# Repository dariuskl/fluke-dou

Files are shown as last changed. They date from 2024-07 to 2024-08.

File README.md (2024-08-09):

# Data Output Units for Vintage Fluke Meters

This is a collection of firmware and PCBs mean to be used in vintage Fluke
meters such as the 8000A, 1900A, etc. They provide the measurements of the
meter on a USB serial port and might also provide other features such as
the possibility to power the meter via that USB port.

The firmware targets the MSP430G2xx series of microcontrollers despite them
being neither vintage nor 5 V devices. They were chosen due to their good
availability, ease-of-use, good compiler support, wide range of package
options (including DIP), and affordability. (Most modern 5V parts just have
internal regulators anyway, due to modern lithography, so we' just be saving
us the level shifting, but some devices require more than a level shifter
anyway.)

Code is written in C, decode logic and platform-specific stuff is separated
as much as possible. So porting this to a different controller should be
straight-forward. The build is run by `make` as a jumbo build.

## 1900A — Multi-Counter

- PCB is already designed
- C++ code exists, also ported here, but not yet tested

See https://github.com/dariuskl/fluke_1900a_usb_dou

## 8000A — Digital Multimeter

**Firmware** — first working version available with tag `8000a-fw-1`
**Hardware** — PCB not yet designed, working on perfboard prototype

The 8000A is a very early multimeter with limited data output capabilities. It
offers only signals for the digits, none for the decimal point or range and
mode information.

The serial output is default configured to 19200 baud 7N1 and transmits the
readings as outlined below.

    <overload><polarity><MSD><2SD><3SD><LSD>\r\n

### Modifications Required for Battery Pack (Option -01)

The battery pack PCB does not have routing for all signals required by the DOU
onto the finger connector. The two-layered board just could not accommodate
both the traces required for the batteries and the DOU. This can be fixed with
a few jumper wires, though.

**TODO: insert a schema showing what points to connect here**

### Finger Connector Pinout

The finger conector is a card edge connector at the back of the main PCB. It
is double-sides, i.e. there might be different signals on the top and bottom
side of the board. Most handily, the Fluke engineers put some pracitcal vias
with a 2.54 mm pitch through ten of those connections, plus one extra via to
the side, but perfectly in grid. This is where a 11-position pin receptable
will find its place.

The signal `nT` is actually not part of the finger connector, but it does have
a strategically placed via. As it is next to pin 1 of the finger connector, I
assigned it the pin number zero.

Not all signals have suitable logic levels to interface to a 5 V µC (let alone
the 3.3 V MSP430), so comparators are used to condition the signals according
to the thresholds that I determined for each signal.

(Note that the given high and low voltage levels are ballpark figures.)

| Pin | Signal | Description | Low level | High level  | Threshold |
|-----|---|---|---|---|---|
| 0 | nT | Measurement period | 1.2 V | 4.8 V | 2.5 V |
| 2 | nZERO  | ??? | | | |
| 4 | S1 | MSD strobe | 0 V | 4.6 V | 2.5 V |
| 6 | S4 | LSD strobe | 0 V | 3.3 V | 1.6 V |
| 8 | S | Strobe clock | 0 V | 2.5...4.6 V | 1.6 V |
| 10  | +5V | Regulated 5V rail  | — | — | — |
| 12  | GND | Ground | — | — | — |
| 14  | Y | BCD 4 | 0 V | 4.9 V | 2.5 V |
| 16  | X | BCD 2 | 0 V | 4.9 V | 2.5 V |
| 18  | W | BCD 8 | 0 V | 4.9 V | 2.5 V |
| 20  | Z | BCD 1 | 0 V | 4.9 V | 2.5 V |

### Protocol

| Digit | W | X | Y | Z | Strobe |
|---|---|---|---|---|---|
| DS1 (MSD) | overload | ? | polarity | MSD | S1 |
| DS2..DS3  | BCD 8 | BCD 4 | BCD 2 | BCD 1 | none |
| DS4 (LSD) | BCD 8 | BCD 4 | BCD 2 | BCD 1 | S4 |

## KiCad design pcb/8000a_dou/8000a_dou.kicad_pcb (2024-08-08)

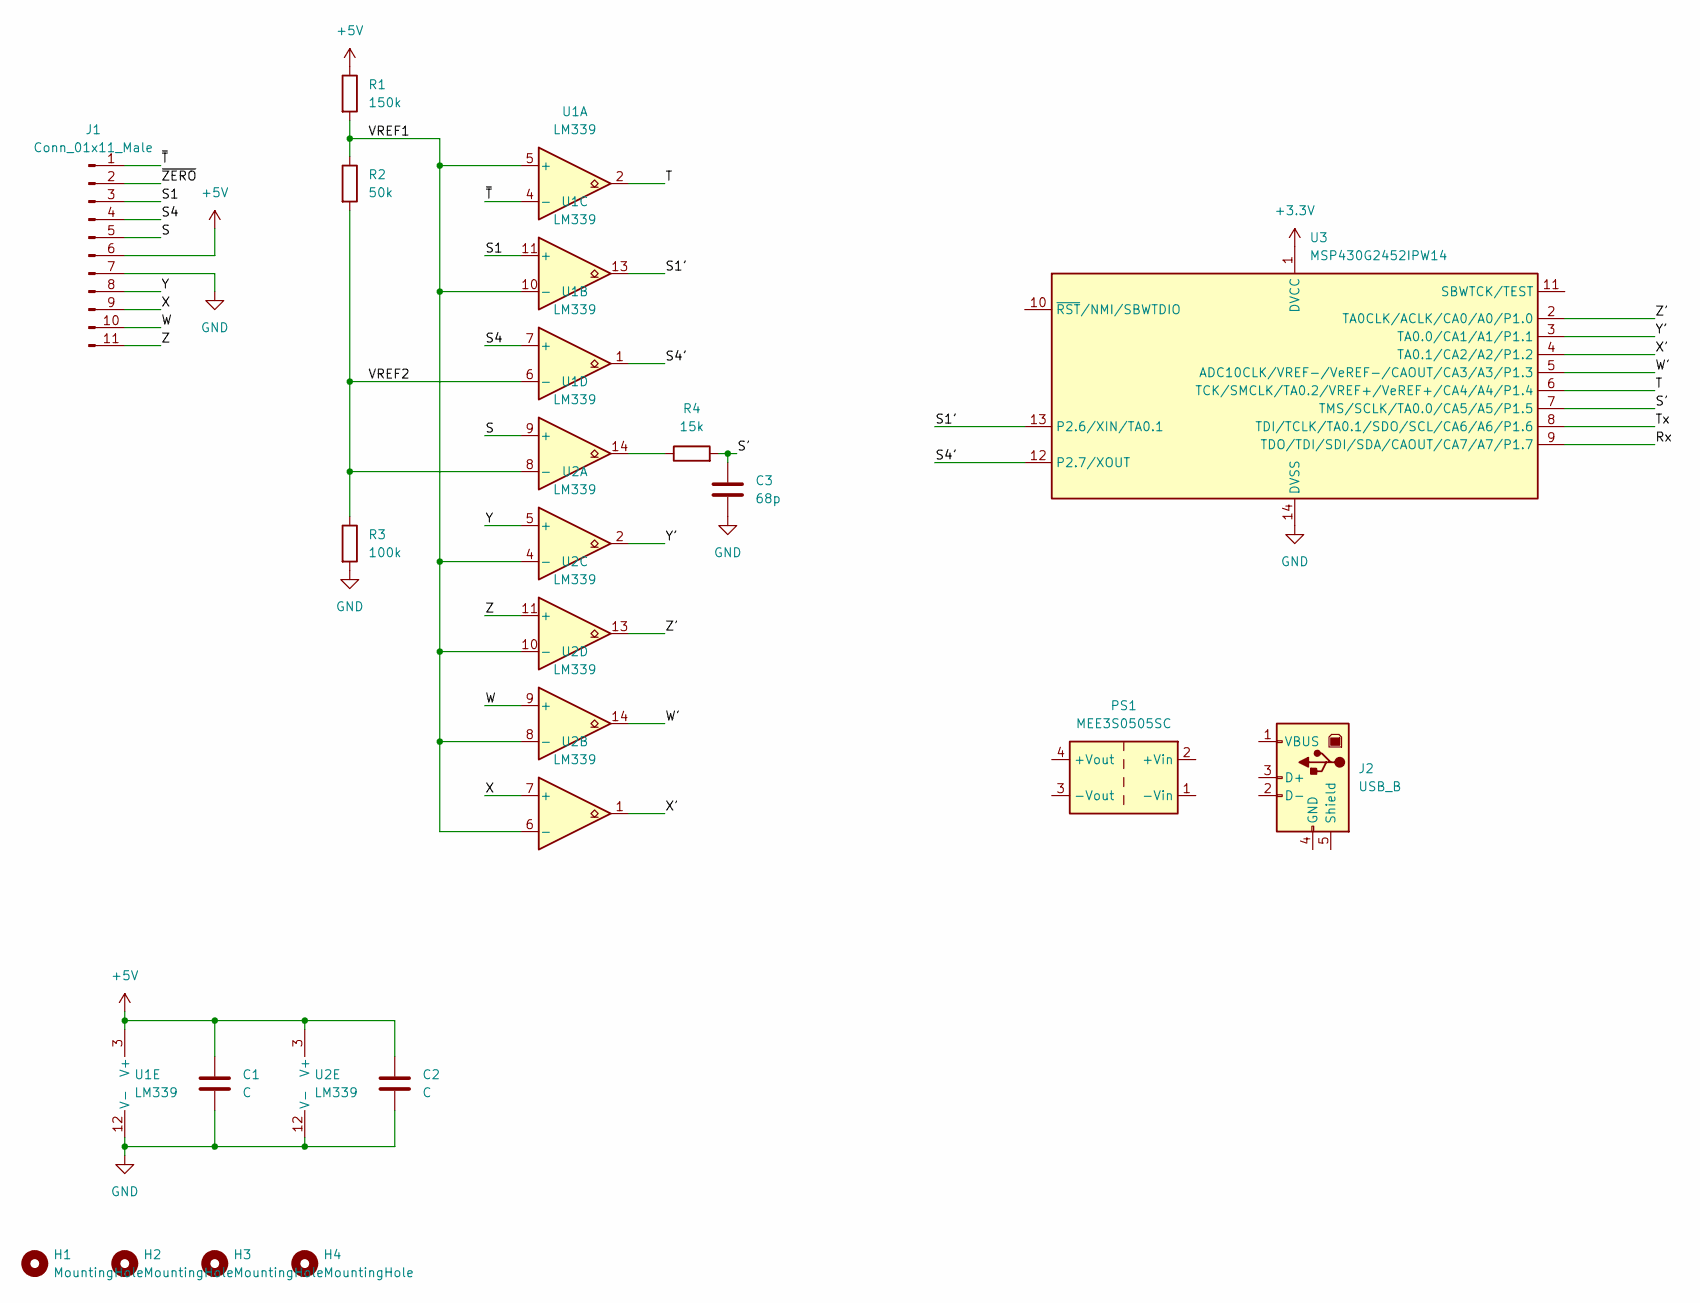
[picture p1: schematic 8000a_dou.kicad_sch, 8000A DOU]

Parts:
C1, C2: C; C_0805_2012Metric
C3: 68p; C_0805_2012Metric
H1, H2, H3, H4: MountingHole; MountingHole_3.2mm_M3
J1: Conn_01x11_Male; PinHeader_1x11_P2.54mm_Vertical
J2: USB_B; USB_B_Lumberg_2411_02_Horizontal
PS1: MEE3S0505SC; Converter_DCDC_Murata_MEE3SxxxxSC_THT
R1: 150k; R_Axial_DIN0207_L6.3mm_D2.5mm_P10.16mm_Horizontal
R2: 50k; R_Axial_DIN0207_L6.3mm_D2.5mm_P10.16mm_Horizontal
R3: 100k; R_Axial_DIN0207_L6.3mm_D2.5mm_P10.16mm_Horizontal
R4: 15k; R_Axial_DIN0207_L6.3mm_D2.5mm_P10.16mm_Horizontal
U1, U2: LM339; SOIC-14_3.9x8.7mm_P1.27mm
U3: MSP430G2452IPW14; TSSOP-14_4.4x5mm_P0.65mm

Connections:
+3V3: U3.1 (DVCC)
+5V: C1.1, C2.1, J1.6, R1.1, U1.3 (V+), U2.3 (V+)
/Rx: U3.9 (TDO/TDI/SDI/SDA/CAOUT/CA7/A7/P1.7)
/S: J1.5, U1.9 (+)
/S1: J1.3, U1.11 (+)
/S1': U1.13, U3.13 (P2.6/XIN/TA0.1)
/S4: J1.4, U1.7 (+)
/S4': U1.1, U3.12 (P2.7/XOUT)
/S': C3.1, R4.2, U3.7 (TMS/SCLK/TA0.0/CA5/A5/P1.5)
/T: U1.2, U3.6 (TCK/SMCLK/TA0.2/VREF+/VeREF+/CA4/A4/P1.4)
/Tx: U3.8 (TDI/TCLK/TA0.1/SDO/SCL/CA6/A6/P1.6)
/VREF1: R1.2, R2.1, U1.5 (+), U1.10 (-), U2.4 (-), U2.6 (-), U2.8 (-), U2.10 (-)
/VREF2: R2.2, R3.1, U1.6 (-), U1.8 (-)
/W: J1.10, U2.9 (+)
/W': U2.14, U3.5 (ADC10CLK/VREF-/VeREF-/CAOUT/CA3/A3/P1.3)
/X: J1.9, U2.7 (+)
/X': U2.1, U3.4 (TA0.1/CA2/A2/P1.2)
/Y: J1.8, U2.5 (+)
/Y': U2.2, U3.3 (TA0.0/CA1/A1/P1.1)
/Z: J1.11, U2.11 (+)
/Z': U2.13, U3.2 (TA0CLK/ACLK/CA0/A0/P1.0)
/~T: J1.1, U1.4 (-)
/~ZERO: J1.2
GND: C1.2, C2.2, C3.2, J1.7, R3.2, U1.12 (V-), U2.12 (V-), U3.14 (DVSS)
unnamed: R4.1, U1.14

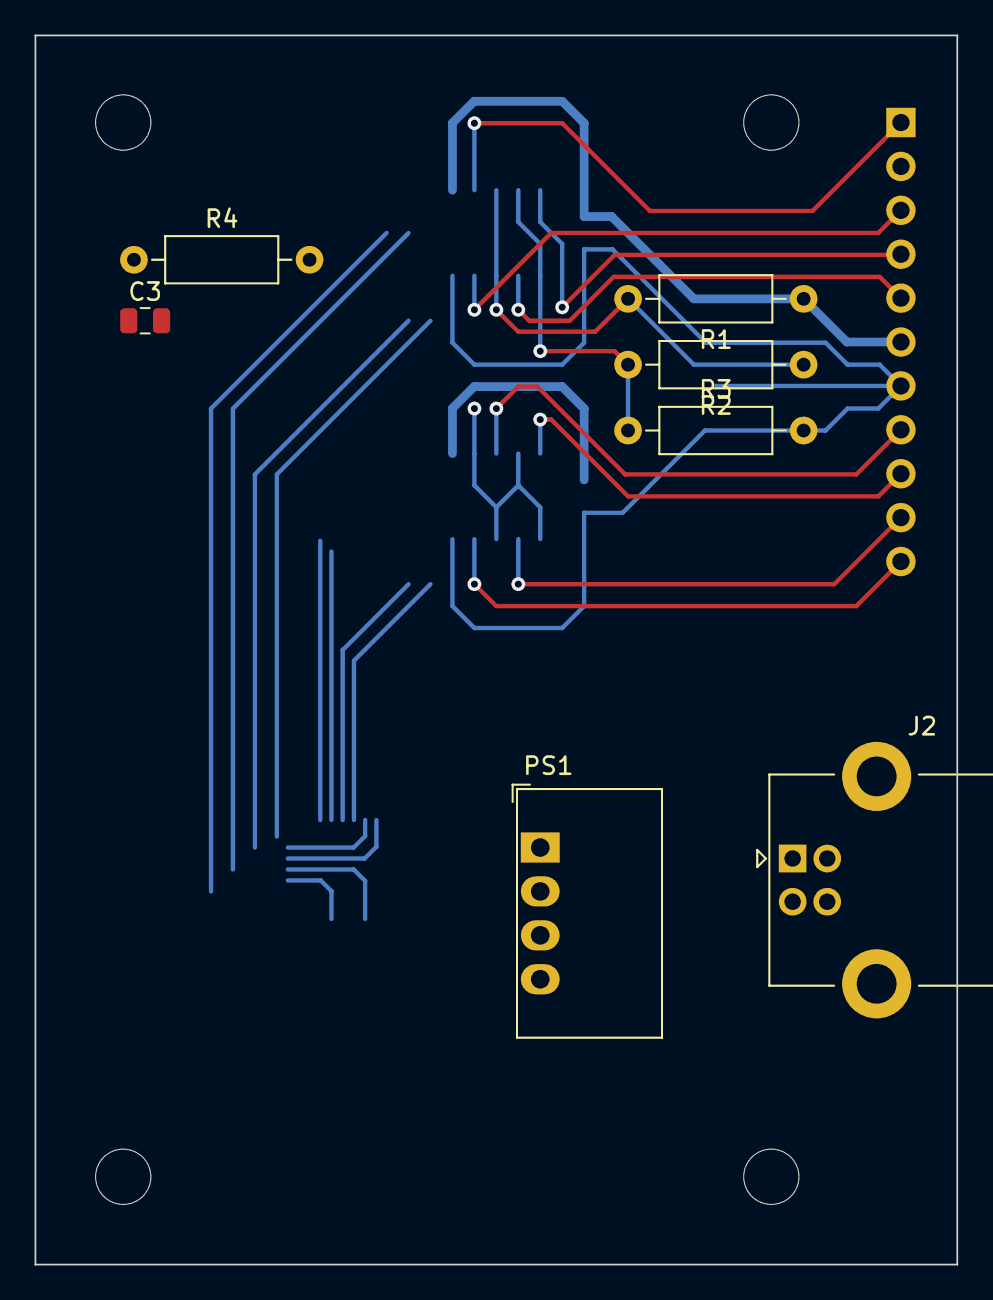
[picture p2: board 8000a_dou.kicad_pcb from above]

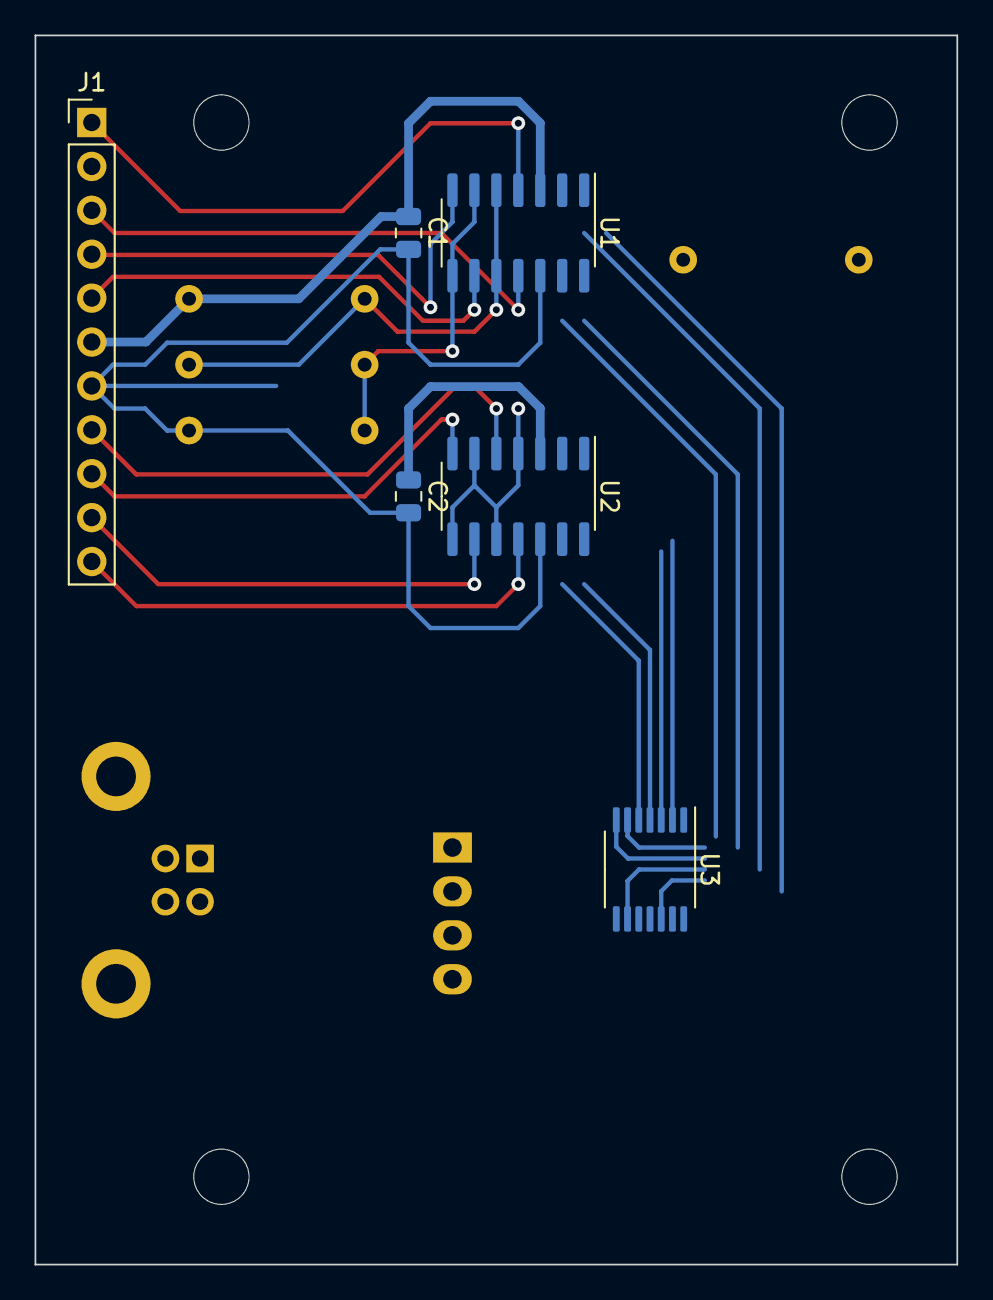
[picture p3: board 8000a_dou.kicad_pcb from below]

Board: 2 copper layers, 53.3 x 71.1 mm, 17 parts (6 on the bottom side), 21 nets.

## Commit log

2024-07-18 lots of progress
    - serial via USI works
    - info util helps re-writing device calibration
    - found out that MSPG2231 has no 16MHz factory calibration
2024-07-21 8000A works mostly; logic levels not OK yet
    [8000a.kicad_pcb, 8000a.kicad_sch]
2024-07-26 debugging the 8000A
    [8000a.kicad_pcb, 8000a.kicad_sch]
2024-07-26 can capture input from 8000A, but ...
    - not every cycle is seeing output on serial
    - readings are consistently output on serial while T is low,
    should be just once
    - watchdog is disabled for now, because it screws up everything
2024-07-27 put low-pass filter on S'
    [8000a.kicad_pcb, 8000a.kicad_sch]
2024-08-08 rename DOU PCB project
    Perhaps further PCBs for the 8000A will be designed or a reproduction of
    the original schematic.
    [8000a_dou.kicad_pcb, 8000a_dou.kicad_sch]
